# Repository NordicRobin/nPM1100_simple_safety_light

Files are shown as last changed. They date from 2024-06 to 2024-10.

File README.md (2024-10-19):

The nPM1100 simple safety light is a concept sketch for using the nPM1100's "ship mode" as the on/off switch for a 
rechargeable bicycle light or other small flashlight. This gives it the simple button-press activation we're used to from 
this type of device, without the need for a microcontroller. \
\
Many rechargeable bicycle lights [needs citation] use some sort of microcontroller to control the charging and on/off functionality, 
as well as different blinking modes of the LEDs on the bicycle lights. In my experience, these microcontrollers tend to drain 
the battery of the light when left unused for a period of time. By using the nPM1100's ship mode
as a power-down mode, the light consumes only 0.45 uA while powered off. This would also be the case if a microcontroller was included in the design, as the 
nPM1100 ship mode cuts power to all devices it's powering while in this mode. \
\
As an extra challenge, the nPM1100's inputs for entering and exiting ship mode have opposite polarities, therefore a simple PNP bipolar junction transistor (BJT) is included to 
flip the polarity of the button press, when the BJT is powered by the nPM1100's regulator. The BJT adds to the current consumption of the light while the circuit is powered on, 
but does not affect the 0.45 uA current draw of the system while in ship mode. 



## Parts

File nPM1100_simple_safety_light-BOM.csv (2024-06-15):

Reference | Quantity | Value | Footprint | Description | Manufacturer | Manufacturer Part Number | Distributor Link | DNP
C1 | 1 | 2u2, 25 V, ±20% | Capacitor_SMD:C_0603_1608Metric | Unpolarized capacitor | Murata Electronics | GRM188R61E225MA12D | https://www.digikey.no/no/products/detail/murata-electronics/GRM188R61E225MA12D/4905351
C2, C3, C4 | 3 | 10u, 6.3 V, ±20% | Capacitor_SMD:C_0603_1608Metric | Unpolarized capacitor | Samsung Electro-Mechanics | CL10A106MQ8NNNC | https://www.digikey.no/no/products/detail/samsung-electro-mechanics/CL10A106MQ8NNNC/3886777
C5 | 1 | 1u, 10 V, ±20% | Capacitor_SMD:C_0201_0603Metric | Unpolarized capacitor | Cal-Chip Electronics, Inc. | GMC02X5R105M10NT | https://www.digikey.no/no/products/detail/cal-chip-electronics-inc/GMC02X5R105M10NT/18151158
D2 | 1 | CHG LED | LED_SMD:LED_0603_1608Metric | Light emitting diode | Lite-On Inc. | LTST-C193KGKT-5A | https://www.digikey.no/no/products/detail/liteon/LTST-C193KGKT-5A/2356242
J1 | 1 | USB_C_Receptacle_USB2.0 | Connector_USB:USB_C_Receptacle_G-Switch_GT-USB-7010ASV | USB 2.0-only Type-C Receptacle connector | Amphenol ICC | 10155435-00011LF | https://www.digikey.no/no/products/detail/amphenol-cs-fci/10155435-00011LF/11602060
L1 | 1 | 2u2 | PCM_Inductor_SMD_AKL:L_0805_2012Metric | Inductor | Murata | DFE201210U-2R2M | https://www.digikey.no/no/products/detail/murata-electronics/DFE201210U-2R2M-P2/7595453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
Q1 | 1 | BC807 | Package_TO_SOT_SMD:SOT-23 | 0.8A Ic, 45V Vce, PNP Transistor, SOT-23 | onsemi | BC807-25LT1G | https://www.digikey.no/no/products/detail/onsemi/BC807-25LT1G/918336
R1 | 1 | 100k, 0.05 W, ±1% | Resistor_SMD:R_0201_0603Metric | Resistor | YAGEO | RC0201FR-07100KL | https://www.digikey.no/no/products/detail/yageo/RC0201FR-07100KL/1948859
R2 | 1 | 1k, 0.05 W, ±1% | Resistor_SMD:R_0201_0603Metric | Resistor | YAGEO | RC0201FR-071KL | https://www.digikey.no/no/products/detail/yageo/RC0201FR-071KL/3202389
R3 | 1 | 22, 0.1 W, ±1% | Resistor_SMD:R_0603_1608Metric | Resistor | YAEGO | RC0603FR-1322RL | https://www.digikey.no/no/products/detail/yageo/RC0603FR-1322RL/13694095
R4, R7 | 2 | 10k, 0.05 W, ±1% | Resistor_SMD:R_0201_0603Metric | Resistor | YAGEO | RC0201FR-0710KL | https://www.digikey.no/no/products/detail/yageo/RC0201FR-0710KL/1948870
R5, R6 | 2 | 5k1, 0.05 W, ±1% | Resistor_SMD:R_0201_0603Metric | Resistor | YAGEO | RC0201FR-075K1L | https://www.digikey.no/no/products/detail/yageo/RC0201FR-075K1L/5280601
U1 | 1 | nPM1100-QDXX | Package_DFN_QFN:QFN-24-1EP_4x4mm_P0.5mm_EP2.6x2.6mm_ThermalVias | PMIC and Battery Charger, QFN-24 | Nordic Semiconductor | NPM1100-QDAA-R | https://www.digikey.no/no/products/detail/nordic-semiconductor-asa/NPM1100-QDAA-R/18069437

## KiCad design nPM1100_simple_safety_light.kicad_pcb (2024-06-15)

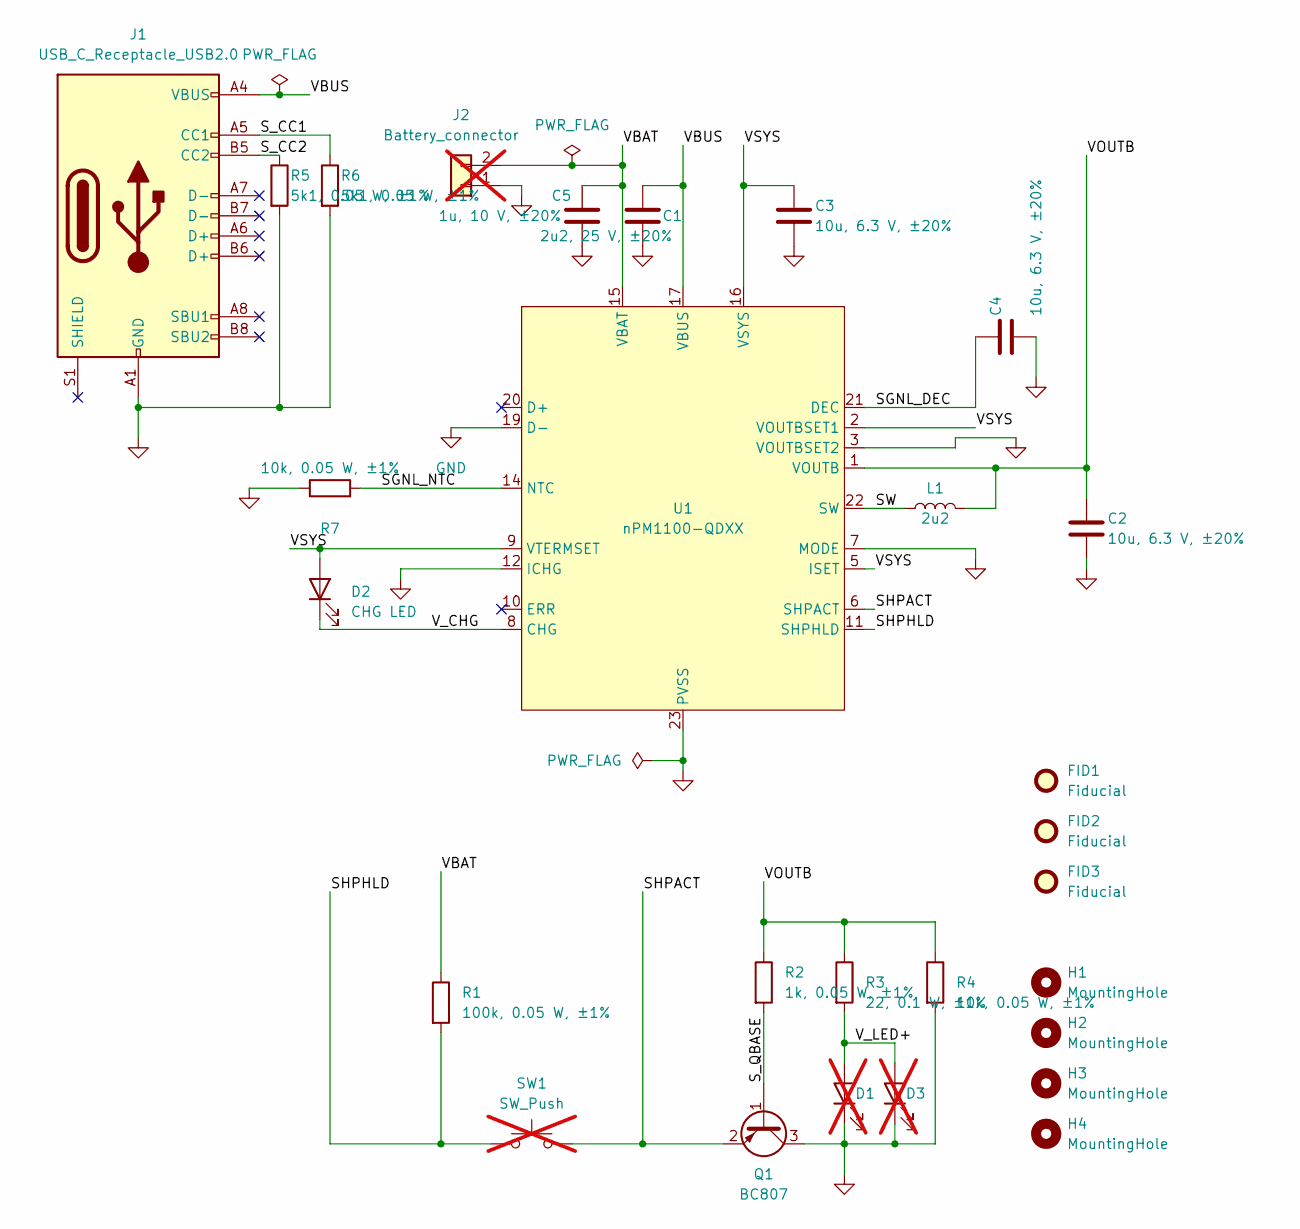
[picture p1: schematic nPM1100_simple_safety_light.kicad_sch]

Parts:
C1: 2u2, 25 V, ±20%; C_0603_1608Metric; Manufacturer Part Number GRM188R61E225MA12D
C2, C3, C4: 10u, 6.3 V, ±20%; C_0603_1608Metric; Manufacturer Part Number CL10A106MQ8NNNC
C5: 1u, 10 V, ±20%; C_0201_0603Metric; Manufacturer Part Number GMC02X5R105M10NT
D1, D3: POWER LED; LED_D5.0mm; not fitted
D2: CHG LED; LED_0603_1608Metric; Manufacturer Part Number LTST-C193KGKT-5A
FID1, FID2, FID3: Fiducial; Fiducial_0.75mm_Mask1.5mm
H1, H2, H3, H4: MountingHole; MountingHole_2.2mm_M2
J1: USB_C_Receptacle_USB2.0; USB_C_Receptacle_G-Switch_GT-USB-7010ASV; Manufacturer Part Number 10155435-00011LF
J2: Battery_connector; PinHeader_1x02_P2.00mm_Vertical; not fitted
L1: 2u2; L_0805_2012Metric; Manufacturer Part Number DFE201210U-2R2M
Q1: BC807; SOT-23; Manufacturer Part Number BC807-25LT1G
R1: 100k, 0.05 W, ±1%; R_0201_0603Metric; Manufacturer Part Number RC0201FR-07100KL
R2: 1k, 0.05 W, ±1%; R_0201_0603Metric; Manufacturer Part Number RC0201FR-071KL
R3: 22, 0.1 W, ±1%; R_0603_1608Metric; Manufacturer Part Number RC0603FR-1322RL
R4, R7: 10k, 0.05 W, ±1%; R_0201_0603Metric; Manufacturer Part Number RC0201FR-0710KL
R5, R6: 5k1, 0.05 W, ±1%; R_0201_0603Metric; Manufacturer Part Number RC0201FR-075K1L
SW1: SW_Push; SW_PUSH_6mm; not fitted
U1: nPM1100-QDXX; QFN-24-1EP_4x4mm_P0.5mm_EP2.6x2.6mm_ThermalVias; Manufacturer Part Number nPM1100-QDAA

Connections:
/SGNL_DEC: C4.1, U1.21 (DEC)
/SGNL_NTC: R7.2, U1.14 (NTC)
/SHPACT: Q1.2 (E), SW1.2, U1.6 (SHPACT)
/SHPHLD: R1.2, SW1.1, U1.11 (SHPHLD)
/SW: L1.1, U1.22 (SW)
/S_CC1: J1.A5 (CC1), R6.1
/S_CC2: J1.B5 (CC2), R5.1
/S_QBASE: Q1.1 (B), R2.2
/VBAT: C5.1, J2.2, R1.1, U1.15 (VBAT)
/VBUS: C1.1, J1.A4 (VBUS), J1.A9 (VBUS), J1.B4 (VBUS), J1.B9 (VBUS), U1.17 (VBUS)
/VOUTB: C2.1, L1.2, R2.1, R3.1, R4.1, U1.1 (VOUTB)
/VSYS: C3.1, D2.2 (A), U1.2 (VOUTBSET1), U1.5 (ISET), U1.9 (VTERMSET), U1.16 (VSYS)
/V_CHG: D2.1 (K), U1.8 (CHG)
/V_LED+: D1.2 (A), D3.2 (A), R3.2
GND: C1.2, C2.2, C3.2, C4.2, C5.2, D1.1 (K), D3.1 (K), J1.A1 (GND), J1.A12 (GND), J1.B1 (GND), J1.B12 (GND), J2.1, Q1.3 (C), R4.2, R5.2, R6.2, R7.1, U1.3 (VOUTBSET2), U1.7 (MODE), U1.12 (ICHG), U1.19 (D-), U1.23 (PVSS), U1.25 (PVSS)

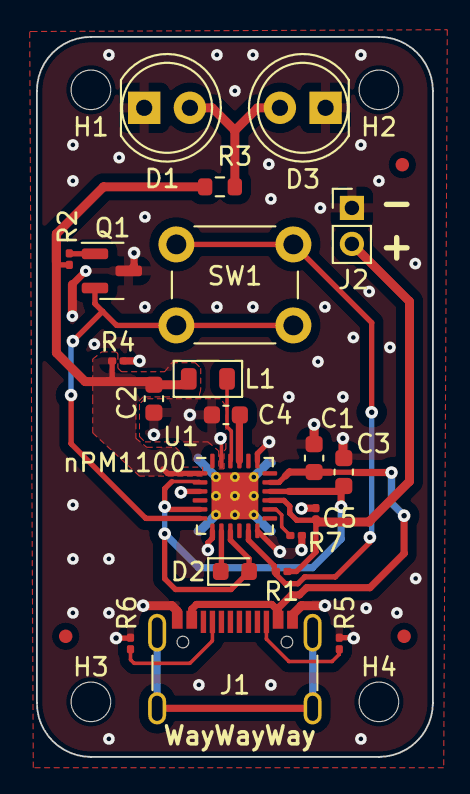
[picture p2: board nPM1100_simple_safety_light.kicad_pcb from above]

Board: 2 copper layers, 22.0 x 40.0 mm, 28 parts (0 on the bottom side), 15 nets.
